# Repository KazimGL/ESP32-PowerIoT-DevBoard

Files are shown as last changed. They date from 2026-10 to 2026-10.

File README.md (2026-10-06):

# ESP32 PowerIoT Dev Board

**A battery-powered ESP32 development board with onboard Li-ion charging, protection, regulation, and sensor support — designed end-to-end in KiCad.**

Designed by **Kazim Bhojani** ([KaizBuilts](#)) — a fresher PCB design project built to learn the complete hardware design workflow from schematic to fabrication-ready Gerbers.

---

## 📋 Overview

This board combines four functional subsystems into a single 2-layer PCB:

| Block | Function |
|---|---|
| **Power** | USB-C input, ESD protection, TP4056 Li-ion charging, DW01A + FS8205A battery protection, AP2112K-3.3 regulation, battery voltage sensing |
| **Processor** | ESP32-WROOM-32E module with reset/boot circuitry |
| **Communication** | CH340C USB-UART bridge with auto-program (DTR/RTS reset) circuit, I2C breakout |
| **I/O** | Dual GPIO breakout headers (1×15 each), user LED, user button, BME280 environmental sensor |

---

## ⚙️ Specs

- **MCU:** ESP32-WROOM-32E (WiFi + Bluetooth)
- **Charging:** TP4056, USB-C input, configurable charge current
- **Protection:** DW01A + FS8205A (overcharge / overdischarge / short-circuit)
- **Regulation:** AP2112K-3.3, 600mA LDO
- **Sensor:** BME280 (temperature, humidity, pressure) over I2C
- **Layers:** 2-layer PCB
- **Design tool:** KiCad 10.0.5
- **Board size:** ~65mm × 50mm

---

## 🖼️ Images

**PCB Layout / Routing**
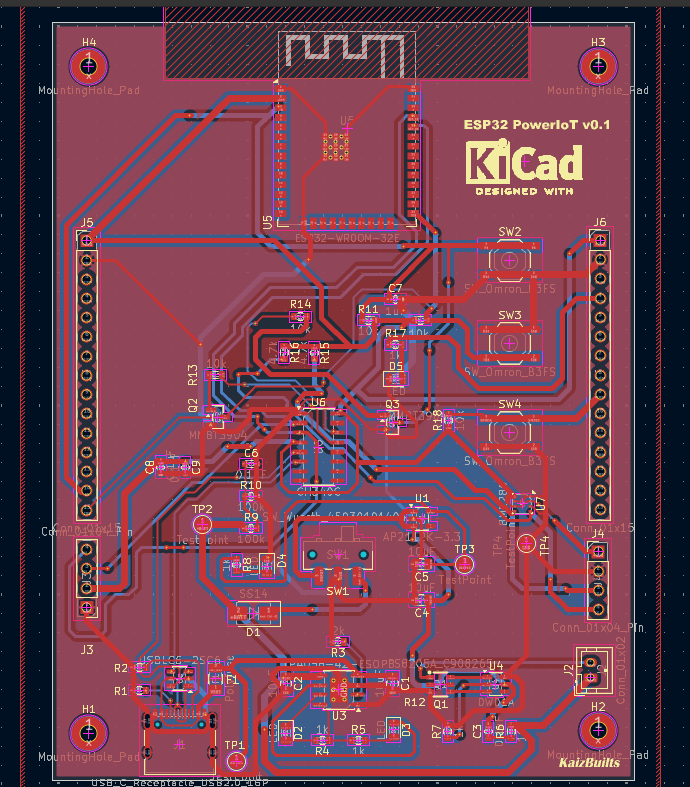
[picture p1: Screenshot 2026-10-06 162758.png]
PCB Routing


**3D Render**
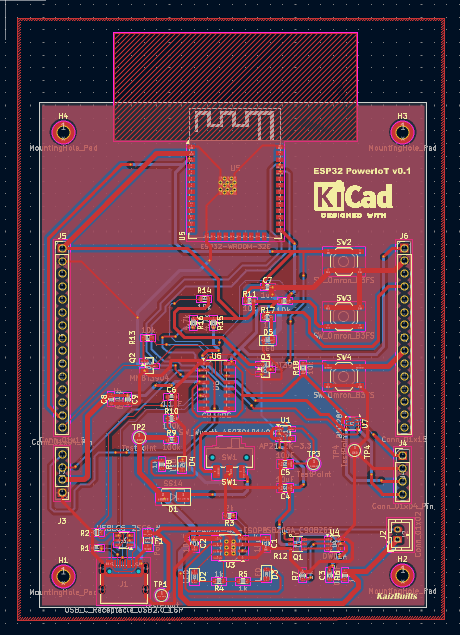
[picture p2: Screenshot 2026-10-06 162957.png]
PCB 3D Render


**Schematic**
📄 [schematic.pdf](schematic.pdf)

**3D Design Overview**
📄 [PRoject_cv.pdf](PRoject_cv.pdf)

---

## 🧠 Design Process & AI-Assisted Workflow

This project was built while learning PCB design fundamentals from scratch, using **Claude (Anthropic)** as a design-review assistant throughout the process — not to generate the design automatically, but to:

- Review each schematic block (Power, Processor, Communication, I/O) for wiring correctness before moving forward
- Explain *why* certain circuits work the way they do (e.g., the EN/IO0 auto-reset logic, battery protection MOSFET gate drive, I2C pull-up sizing)
- Walk through ERC/DRC error messages line-by-line and explain root causes rather than just handing over a fix
- Catch real mistakes along the way (several were my own, and at least one was the AI's — an incorrect DTR/RTS pin mapping that was caught and corrected by cross-checking against esptool's actual reset sequence rather than assumption)

This was an intentionally iterative process: wire a section → verify in ERC → get it reviewed → fix → repeat. Every connection in this board was manually drawn, checked, and understood — the AI's role was review and explanation, not auto-generation.

---

## 🐛 Real Issues Faced During This Build

Documenting these because they were the most time-consuming (and most educational) parts of the project:

1. **KiCad global symbol library table accidentally broken** — while trying to fix a missing footprint library path, the entire global symbol library table collapsed down to a single broken entry, causing 72 cascading ERC warnings across unrelated components (`power`, `Diode`, `Switch`, `Connector` libraries all failed to load). Fixed using KiCad's **"Reset Libraries"** button in the Symbol Libraries manager.

2. **Custom part (FS8205A) had no native KiCad footprint** — imported via `easyeda2kicad` from its LCSC part number, which required linking both a symbol library *and* a separate footprint library (`.pretty` folder) through two different dialogs in two different KiCad editors (Schematic Editor vs. PCB Editor) — not obvious at first.

3. **Duplicate global labels merging unrelated nets** — reused generic labels like `INPUT` and `OUTPUT` in multiple places on the schematic, which KiCad silently merged into a single net across the whole sheet, causing misleading ERC warnings until traced back and renamed to unique, meaningful net names (`VBUS_FUSED`, `3V3`, `-BATT`, etc).

4. **USB-C footprint/symbol pin-count mismatch** — J1 was assigned a 6-pin "power only" USB-C footprint while the schematic symbol used the full 16-pin USB 2.0 pinout (including D+/D−), causing 10 pad-not-found errors during PCB sync. Fixed by selecting the correct 16-pin footprint (`USB_C_Receptacle_HRO_TYPE-C-31-M-12`) matching the real connector's datasheet.

5. **Invalid reference designators blocking PCB sync** — two LED symbols were accidentally named `Green(Done)1` and `RED(charging)1` instead of standard alphanumeric designators, which KiCad's schematic/ERC tolerated but the PCB sync step rejected outright. Renamed to proper `D4`/`D5` format.

6. **DRC hole-size violation on the ESP32 module footprint** — the ESP32-WROOM-32E footprint's castellated pads required a 0.2mm minimum drill size, but the board's design rules were set to a 0.3mm minimum, causing 21 repeated violations. Resolved by adjusting the board's minimum drill size constraint to match both the footprint and the target fab's actual capability.

7. **Incomplete thermal relief connections** on copper pour zones for small shield/ground pads — fixed by reducing the thermal relief gap and spoke width settings to better fit smaller pad geometries.

Each of these was worked through methodically: understand the error → identify root cause → fix → re-verify, rather than blindly applying fixes.

---

## 📁 Repository Contents

```
project_CV.kicad_pro    → KiCad project file
project_CV.kicad_sch    → Schematic source
project_CV.kicad_pcb    → PCB layout source
schematic.pdf           → Exported schematic (all 4 blocks)
PRoject_cv.pdf          → Full project document
*.png                   → PCB layout / 3D render screenshots
README.md               → This file
```

---

## 🔧 Tools Used

- **KiCad 10.0.5** — schematic capture, PCB layout, DRC/ERC
- **easyeda2kicad** — custom part import (FS8205A battery protection MOSFET)
- **Claude (Anthropic)** — design review and debugging assistant

---

---

*Built as a learning project to understand the full PCB design lifecycle — schematic capture, component selection, DFM, fabrication file generation, and bring-up — end to end.*

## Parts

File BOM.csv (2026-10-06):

Reference | Qty | Value | DNP | Exclude from BOM | Exclude from Board | Exclude from Simulation | Exclude from Position Files | Footprint | Datasheet
C1,C2,C4,C5 | 4 | 10uF |  |  |  |  | ${EXCLUDE_FROM_POS_FILES} | Capacitor_SMD:C_0805_2012Metric
C3,C6,C8,C9 | 4 | 0.1uF |  |  |  |  | ${EXCLUDE_FROM_POS_FILES} | Capacitor_SMD:C_0603_1608Metric
C7 | 1 | 1uF |  |  |  |  | ${EXCLUDE_FROM_POS_FILES} | Capacitor_SMD:C_0603_1608Metric
D1 | 1 | SS14 |  |  |  |  | ${EXCLUDE_FROM_POS_FILES} | Diode_SMD:D_SMA | https://www.vishay.com/docs/88746/ss12.pdf
D2,D3,D4,D5 | 4 | LED |  |  |  |  | ${EXCLUDE_FROM_POS_FILES} | LED_SMD:LED_0805_2012Metric
F1 | 1 | Polyfuse |  |  |  |  | ${EXCLUDE_FROM_POS_FILES} | Fuse:Fuse_1206_3216Metric
J1 | 1 | USB_C_Receptacle_USB2.0_16P |  |  |  |  | ${EXCLUDE_FROM_POS_FILES} | Connector_USB:USB_C_Receptacle_HRO_TYPE-C-31-M-12 | https://www.usb.org/sites/default/files/documents/usb_type-c.zip
J2 | 1 | Conn_01x02 |  |  |  |  | ${EXCLUDE_FROM_POS_FILES} | Connector_JST:JST_PH_B2B-PH-K_1x02_P2.00mm_Vertical
J3,J4 | 2 | Conn_01x04_Pin |  |  |  |  | ${EXCLUDE_FROM_POS_FILES} | Connector_PinHeader_2.54mm:PinHeader_1x04_P2.54mm_Vertical
J5,J6 | 2 | Conn_01x15 |  |  |  |  | ${EXCLUDE_FROM_POS_FILES} | Connector_PinHeader_2.54mm:PinHeader_1x15_P2.54mm_Vertical
Q1 | 1 | FS8205A_C908265 |  |  |  |  | ${EXCLUDE_FROM_POS_FILES} | FS8205A_lib:SOT-23-6_L2.9-W1.6-P0.95-LS2.8-BR | https://lcsc.com/product-detail/MOSFET_FUXINSEMI-FS8205A_C908265.html
Q2,Q3 | 2 | MMBT3904 |  |  |  |  | ${EXCLUDE_FROM_POS_FILES} | Package_TO_SOT_SMD:SOT-23 | https://www.onsemi.com/pdf/datasheet/pzt3904-d.pdf
R1,R2 | 2 | 5.1k |  |  |  |  | ${EXCLUDE_FROM_POS_FILES} | Resistor_SMD:R_0603_1608Metric
R3 | 1 | 2k |  |  |  |  | ${EXCLUDE_FROM_POS_FILES} | Resistor_SMD:R_0603_1608Metric
R4,R5,R7,R8,R17 | 5 | 1k |  |  |  |  | ${EXCLUDE_FROM_POS_FILES} | Resistor_SMD:R_0603_1608Metric
R6 | 1 | 100 |  |  |  |  | ${EXCLUDE_FROM_POS_FILES} | Resistor_SMD:R_0603_1608Metric
R9,R10 | 2 | 100k |  |  |  |  | ${EXCLUDE_FROM_POS_FILES} | Resistor_SMD:R_0603_1608Metric
R11,R12,R13,R14,R18 | 5 | 10k |  |  |  |  | ${EXCLUDE_FROM_POS_FILES} | Resistor_SMD:R_0603_1608Metric
R15,R16 | 2 | 4.7k |  |  |  |  | ${EXCLUDE_FROM_POS_FILES} | Resistor_SMD:R_0603_1608Metric
SW1 | 1 | SW_Wuerth_450301014042 |  |  |  |  | ${EXCLUDE_FROM_POS_FILES} | Button_Switch_SMD:SW_SPDT_CK_JS102011SAQN | https://www.we-online.com/components/products/datasheet/450301014042.pdf
SW2,SW3,SW4 | 3 | SW_Omron_B3FS |  |  |  |  | ${EXCLUDE_FROM_POS_FILES} | Button_Switch_SMD:SW_SPST_TL3342 | https://omronfs.omron.com/en_US/ecb/products/pdf/en-b3fs.pdf
TP1,TP2,TP3,TP4 | 4 | TestPoint |  |  |  |  | ${EXCLUDE_FROM_POS_FILES} | TestPoint:TestPoint_Pad_D2.0mm
U1 | 1 | AP2112K-3.3 |  |  |  |  | ${EXCLUDE_FROM_POS_FILES} | Package_TO_SOT_SMD:SOT-23-5 | https://www.diodes.com/assets/Datasheets/AP2112.pdf
U2 | 1 | USBLC6-2SC6 |  |  |  |  | ${EXCLUDE_FROM_POS_FILES} | Package_TO_SOT_SMD:SOT-23-6 | https://www.st.com/resource/en/datasheet/usblc6-2.pdf
U3 | 1 | TP4056-42-ESOP8 |  |  |  |  | ${EXCLUDE_FROM_POS_FILES} | Package_SO:SOIC-8-1EP_3.9x4.9mm_P1.27mm_EP2.41x3.3mm_ThermalVias | https://www.lcsc.com/datasheet/lcsc_datasheet_2410121619_TOPPOWER-Nanjing-Extension-Microelectronics-TP4056-42-ESOP8_C16581.pdf
U4 | 1 | DW01A |  |  |  |  | ${EXCLUDE_FROM_POS_FILES} | Package_TO_SOT_SMD:SOT-23-6 | https://hmsemi.com/downfile/DW01A.PDF
U5 | 1 | ESP32-WROOM-32E |  |  |  |  | ${EXCLUDE_FROM_POS_FILES} | RF_Module:ESP32-WROOM-32E | https://www.espressif.com/sites/default/files/documentation/esp32-wroom-32e_esp32-wroom-32ue_datasheet_en.pdf
U6 | 1 | CH340C |  |  |  |  | ${EXCLUDE_FROM_POS_FILES} | Package_SO:SOIC-16_3.9x9.9mm_P1.27mm | https://datasheet.lcsc.com/szlcsc/Jiangsu-Qin-Heng-CH340C_C84681.pdf
U7 | 1 | BME280 |  |  |  |  | ${EXCLUDE_FROM_POS_FILES} | Package_LGA:Bosch_LGA-8_2.5x2.5mm_P0.65mm_ClockwisePinNumbering | https://www.bosch-sensortec.com/media/boschsensortec/downloads/datasheets/bst-bme280-ds002.pdf

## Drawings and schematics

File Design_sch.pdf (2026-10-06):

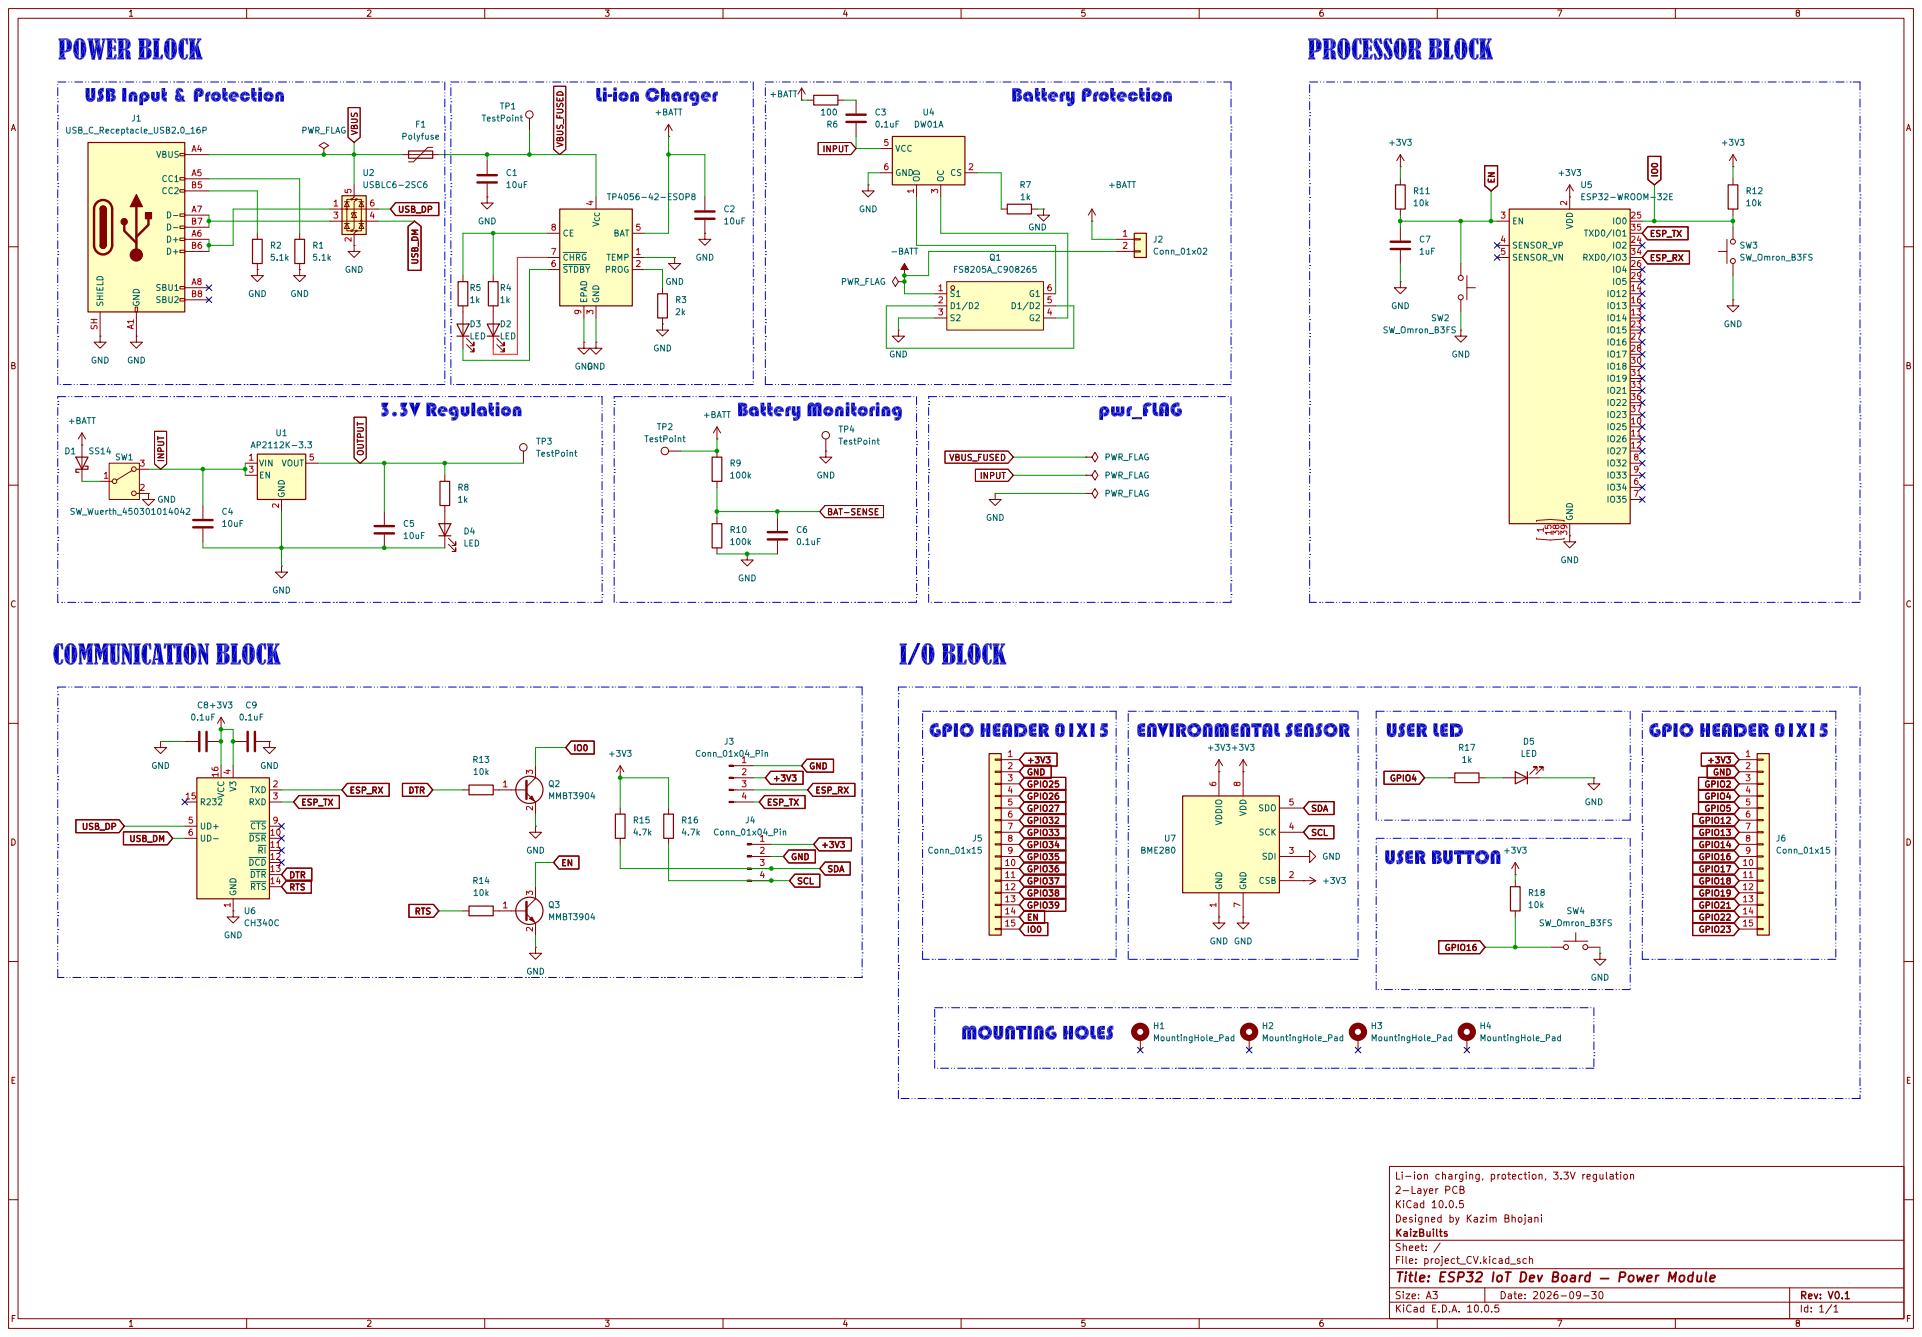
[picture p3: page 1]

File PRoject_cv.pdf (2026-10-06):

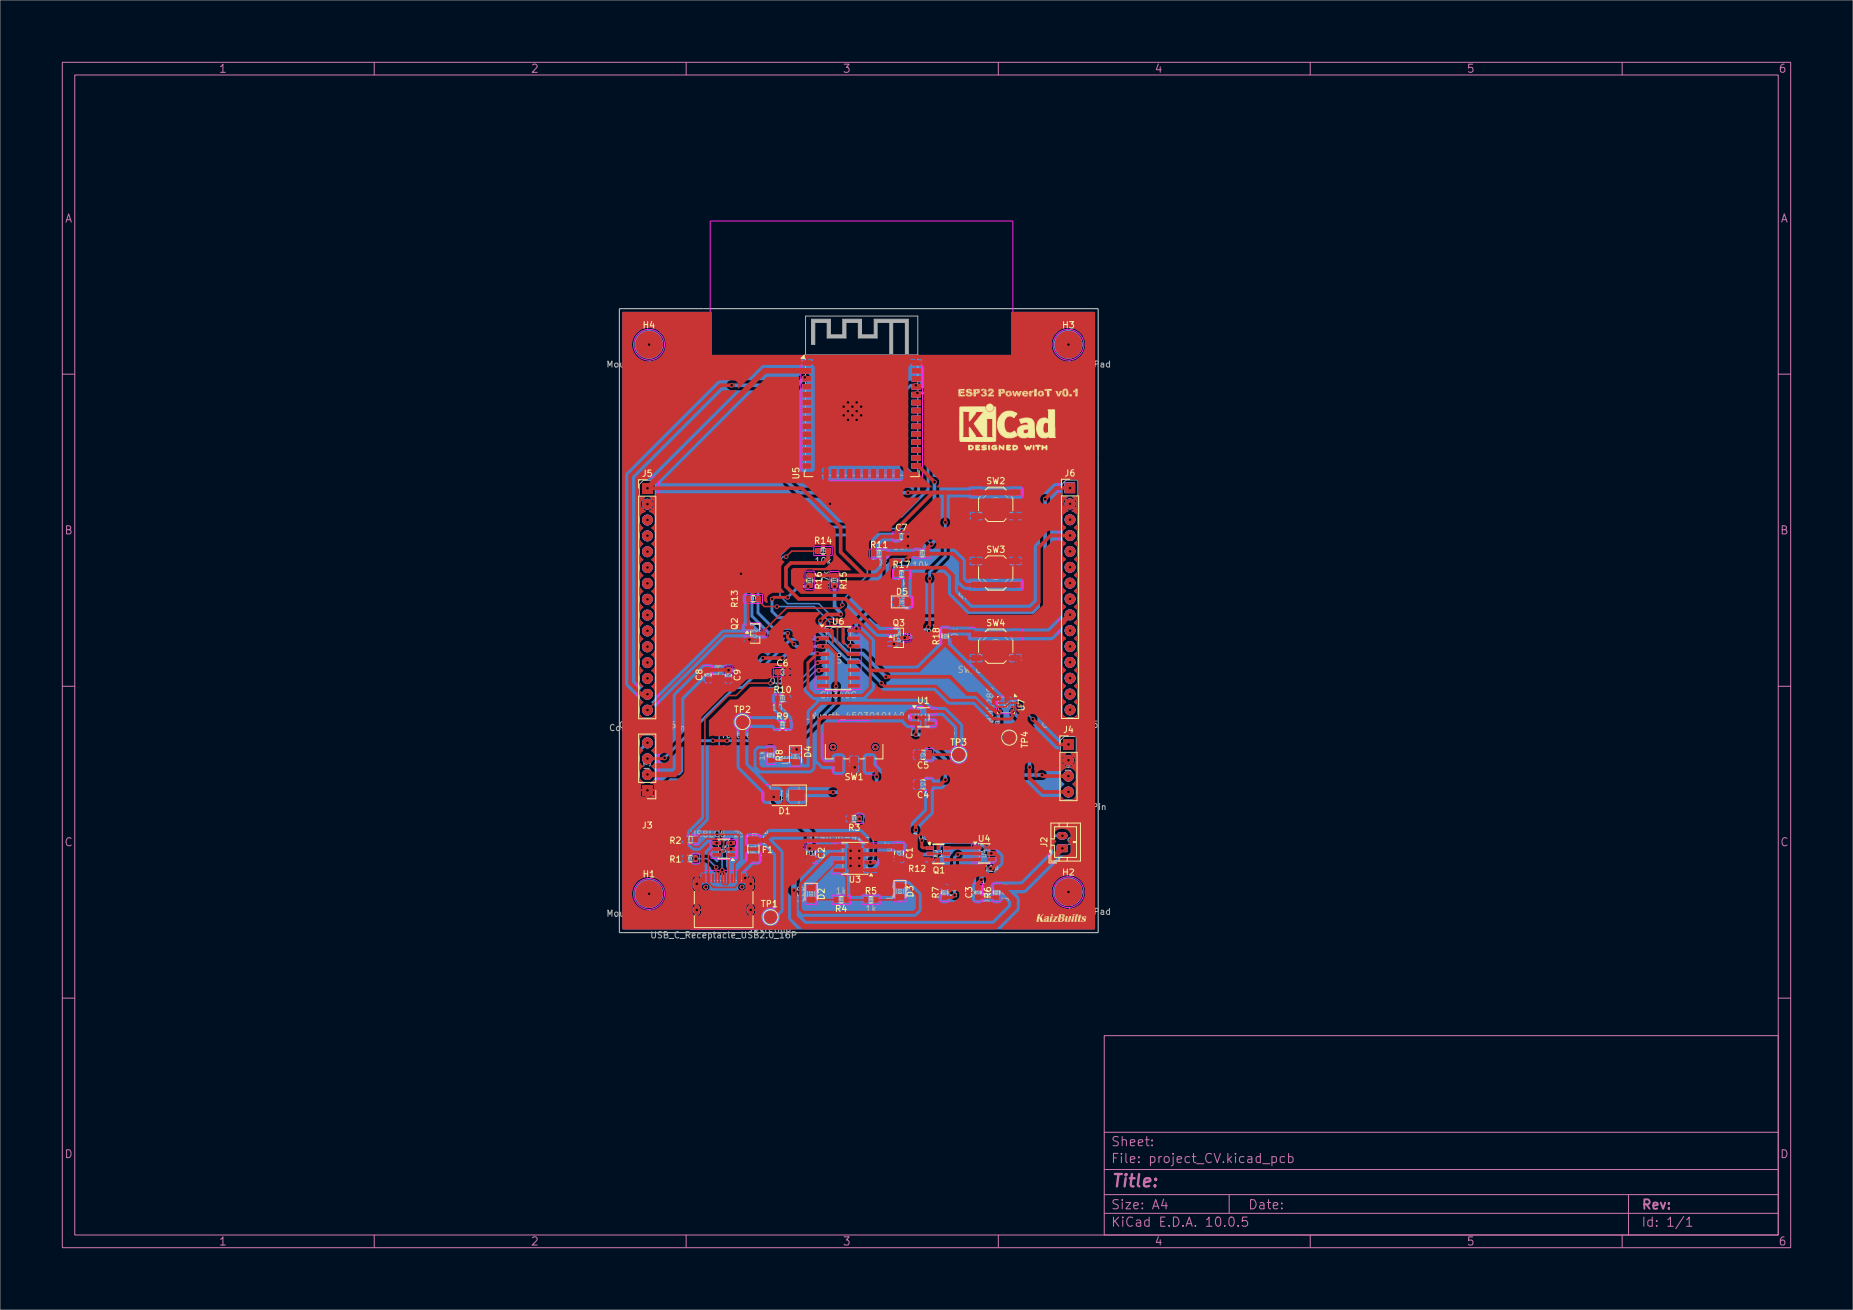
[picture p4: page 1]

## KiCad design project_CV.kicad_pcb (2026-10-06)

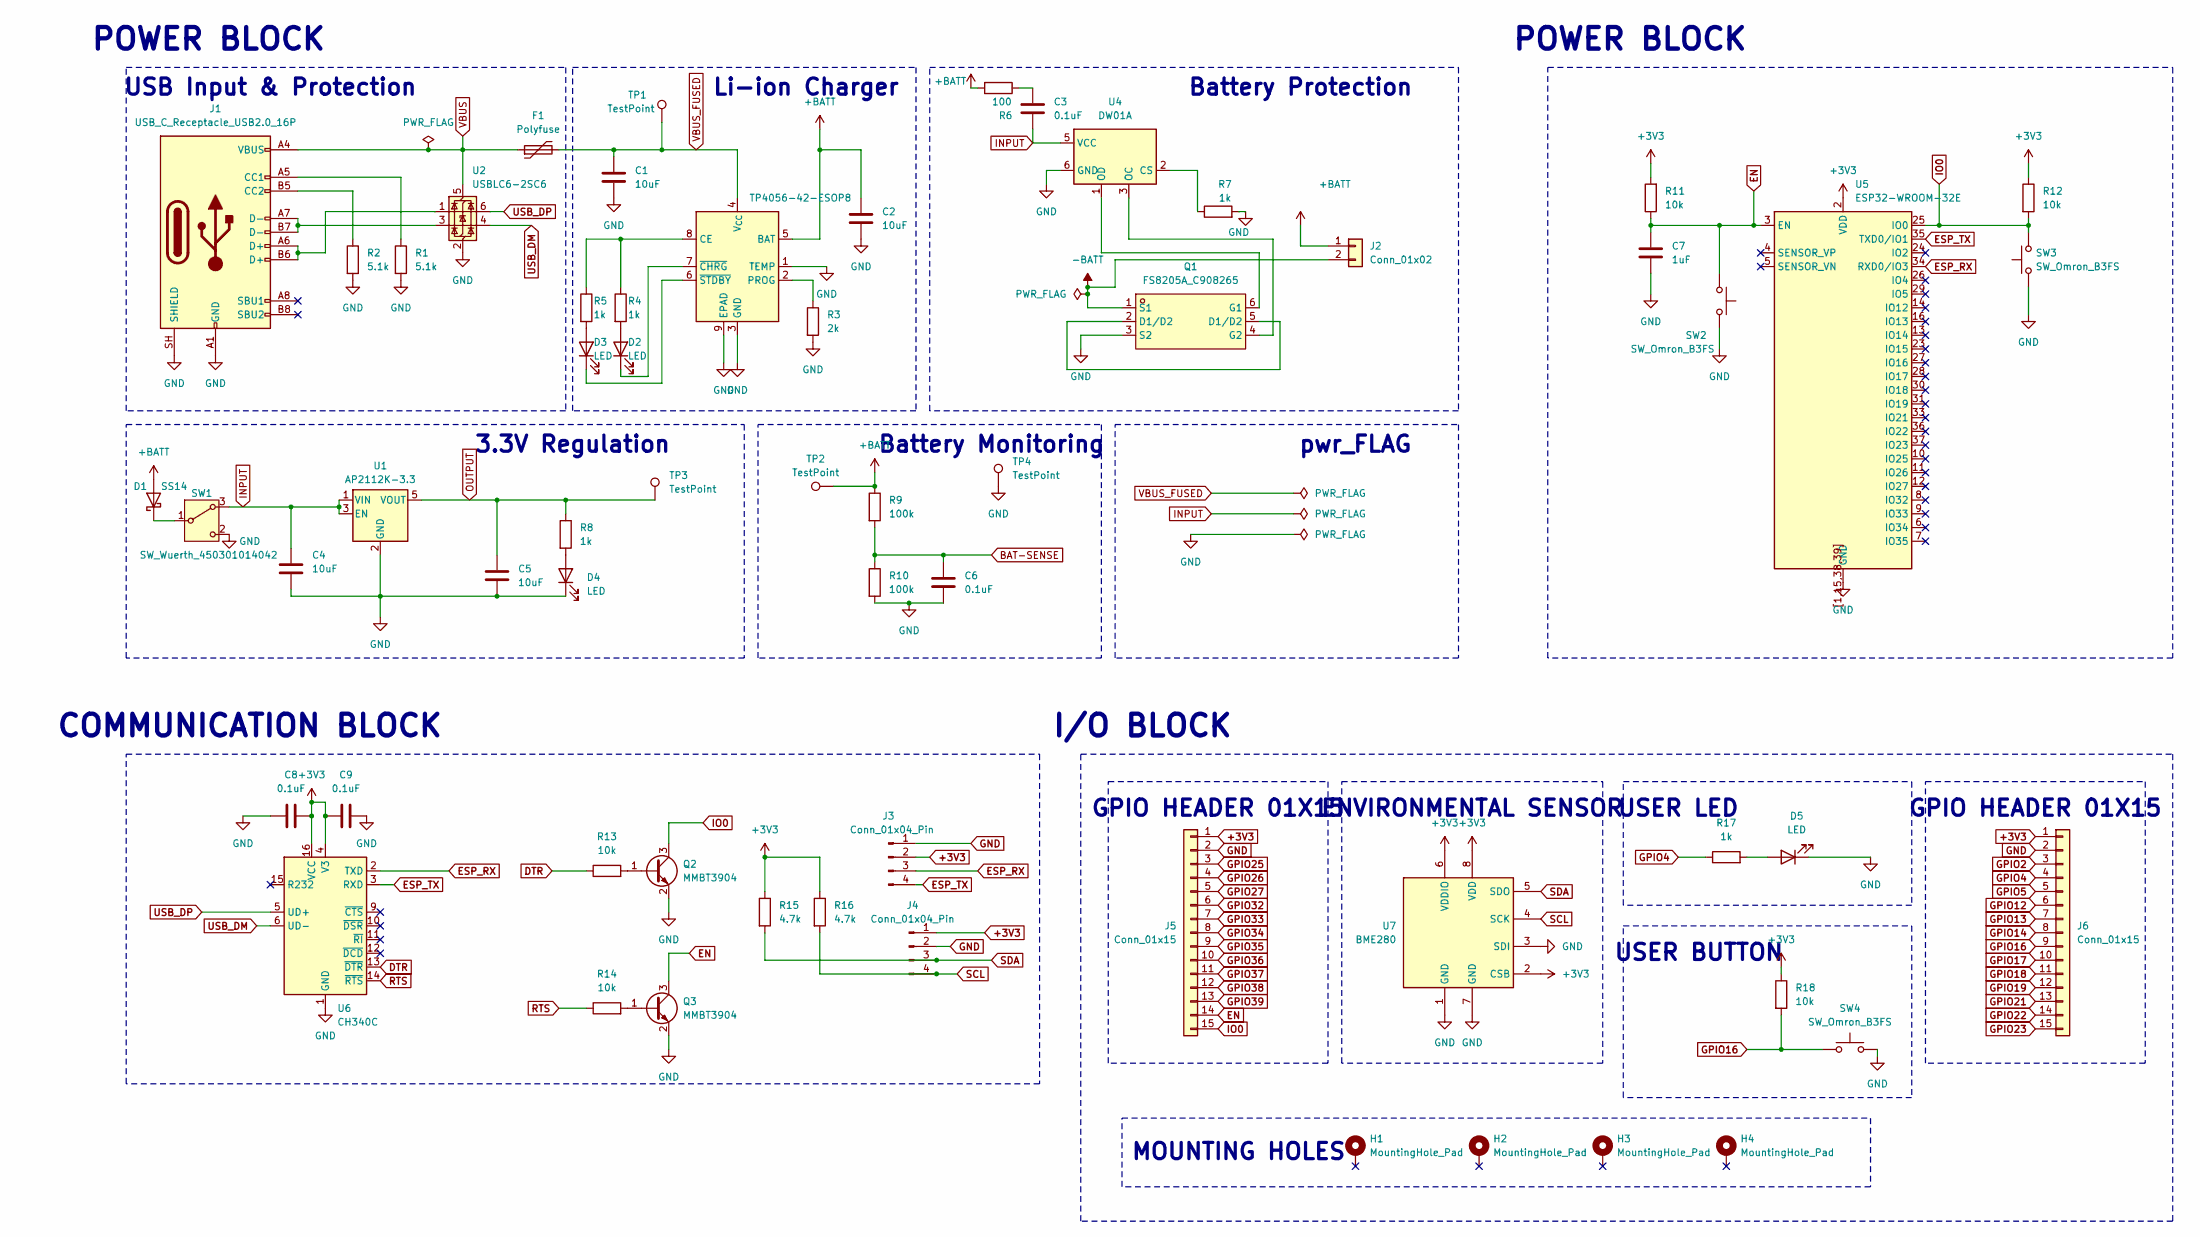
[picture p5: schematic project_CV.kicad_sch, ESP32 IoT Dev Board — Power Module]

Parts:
C1, C2, C4, C5: 10uF; C_0805_2012Metric
C3, C6, C8, C9: 0.1uF; C_0603_1608Metric
C7: 1uF; C_0603_1608Metric
D1: SS14; D_SMA
D2, D3, D4, D5: LED; LED_0805_2012Metric
F1: Polyfuse; Fuse_1206_3216Metric
H1, H2, H3, H4: MountingHole_Pad; MountingHole_2.2mm_M2_Pad
J1: USB_C_Receptacle_USB2.0_16P; USB_C_Receptacle_HRO_TYPE-C-31-M-12
J2: Conn_01x02; JST_PH_B2B-PH-K_1x02_P2.00mm_Vertical
J3, J4: Conn_01x04_Pin; PinHeader_1x04_P2.54mm_Vertical
J5, J6: Conn_01x15; PinHeader_1x15_P2.54mm_Vertical
Q1: FS8205A_C908265; SOT-23-6_L2.9-W1.6-P0.95-LS2.8-BR; MPN FS8205A; LCSC Part C908265
Q2, Q3: MMBT3904; SOT-23
R1, R2: 5.1k; R_0603_1608Metric
R3: 2k; R_0603_1608Metric
R4, R5, R7, R8, R17: 1k; R_0603_1608Metric
R6: 100; R_0603_1608Metric
R9, R10: 100k; R_0603_1608Metric
R11, R12, R13, R14, R18: 10k; R_0603_1608Metric
R15, R16: 4.7k; R_0603_1608Metric
SW1: SW_Wuerth_450301014042; SW_SPDT_CK_JS102011SAQN
SW2, SW3, SW4: SW_Omron_B3FS; SW_SPST_TL3342
TP1, TP2, TP3, TP4: TestPoint; TestPoint_Pad_D2.0mm
U1: AP2112K-3.3; SOT-23-5
U2: USBLC6-2SC6; SOT-23-6
U3: TP4056-42-ESOP8; SOIC-8-1EP_3.9x4.9mm_P1.27mm_EP2.41x3.3mm_ThermalVias
U4: DW01A; SOT-23-6
U5: ESP32-WROOM-32E
U6: CH340C; SOIC-16_3.9x9.9mm_P1.27mm
U7: BME280; Bosch_LGA-8_2.5x2.5mm_P0.65mm_ClockwisePinNumbering

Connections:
+3V3: C8.2, C9.1, J3.2, J4.1, J5.1, J6.1, R11.2, R12.1, R15.1, R16.1, R18.1, U5.2 (VDD), U6.4 (V3), U6.16 (VCC), U7.2 (CSB), U7.6 (VDDIO), U7.8 (VDD)
+BATT: C2.1, D1.2 (A), J2.1, R6.2, R9.1, TP2.1 (1_1), U3.5 (BAT)
-BATT: J2.2, Q1.1 (S1)
BAT-SENSE: C6.1, R9.2, R10.1
DTR: R13.1, U6.13 (~DTR)
EN: C7.1, J5.14, Q3.3 (C), R11.1, SW2.1, U5.3 (EN)
ESP_RX: J3.3, U5.34 (RXD0/IO3), U6.2 (TXD)
ESP_TX: J3.4, U5.35 (TXD0/IO1), U6.3 (RXD)
GND: C1.2, C2.2, C4.2, C5.2, C6.2, C7.2, C8.1, C9.2, D4.1 (K), D5.1 (K), J1.A1 (GND), J1.A12 (GND), J1.B1 (GND), J1.B12 (GND), J1.SH (SHIELD), J3.1, J4.2, J5.2, J6.2, Q1.3 (S2), Q2.2 (E), Q3.2 (E), R1.2, R2.2, R3.2, R7.2, R10.2, SW1.2 (C), SW2.2, SW3.1, SW4.2, TP4.1 (1_1), U1.2 (GND), U2.2 (GND), U3.1 (TEMP), U3.3 (GND), U3.9 (EPAD), U4.6 (GND), U5.1 (GND), U5.15 (GND), U5.38 (GND), U5.39 (GND), U5.[1,15,38,39] (GND), U6.1 (GND), U7.1 (GND), U7.3 (SDI), U7.7 (GND); also elsewhere on the board
GPIO2: J6.3
GPIO4: J6.4, R17.1
GPIO5: J6.5
GPIO12: J6.6
GPIO13: J6.7
GPIO14: J6.8
GPIO16: J6.9, R18.2, SW4.1
GPIO17: J6.10
GPIO18: J6.11
GPIO19: J6.12
GPIO21: J6.13
GPIO22: J6.14
GPIO23: J6.15
GPIO25: J5.3
GPIO26: J5.4
GPIO27: J5.5
GPIO32: J5.6
GPIO33: J5.7
GPIO34: J5.8
GPIO35: J5.9
GPIO36: J5.10
GPIO37: J5.11
GPIO38: J5.12
GPIO39: J5.13
INPUT: C3.2, C4.1, SW1.3 (A), U1.1 (VIN), U1.3 (EN), U4.5 (VCC)
IO0: J5.15, Q2.3 (C), R12.2, SW3.2, U5.25 (IO0)
unnamed: C3.1, R6.1
unnamed: D1.1 (K), SW1.1 (B)
unnamed: D2.2 (A), R4.2
unnamed: D2.1 (K), U3.7 (~CHRG)
unnamed: D3.2 (A), R5.2
unnamed: D3.1 (K), U3.6 (~STDBY)
unnamed: D4.2 (A), R8.2
unnamed: D5.2 (A), R17.2
unnamed: J1.A5 (CC1), R1.1
unnamed: J1.B5 (CC2), R2.1
unnamed 45: J1.A6 (D+), J1.B6 (D+), U2.1 (I/O1); also elsewhere on the board
unnamed 46: J1.A7 (D-), J1.B7 (D-), U2.3 (I/O2); also elsewhere on the board
unnamed: Q1.2 (D1/D2), Q1.5 (D1/D2)
unnamed: Q1.6 (G1), U4.1 (OD)
unnamed: Q1.4 (G2), U4.3 (OC)
unnamed: Q2.1 (B), R13.2
unnamed: Q3.1 (B), R14.2
unnamed: R4.1, R5.1, U3.8 (CE)
unnamed: R3.1, U3.2 (PROG)
unnamed: R7.1, U4.2 (CS)
OUTPUT: C5.1, R8.1, TP3.1 (1_1), U1.5 (VOUT)
RTS: R14.1, U6.14 (~RTS)
SCL: J4.4, R16.2, U7.4 (SCK)
SDA: J4.3, R15.2, U7.5 (SDO)
USB_DM: U2.4 (I/O2), U6.6 (UD-); also elsewhere on the board
USB_DP: U2.6 (I/O1), U6.5 (UD+); also elsewhere on the board
VBUS: F1.1, J1.A4 (VBUS), J1.A9 (VBUS), J1.B4 (VBUS), J1.B9 (VBUS), U2.5 (VBUS); also elsewhere on the board
VBUS_FUSED: C1.1, F1.2, TP1.1 (1_1), U3.4 (V_{CC})

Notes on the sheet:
3.3V Regulation
COMMUNICATION BLOCK
USER BUTTON
GPIO HEADER 01X15
I/O BLOCK
Battery Monitoring
USER LED
POWER BLOCK
Li-ion Charger
ENVIRONMENTAL SENSOR
USB Input & Protection
pwr_FLAG
MOUNTING HOLES
Battery Protection

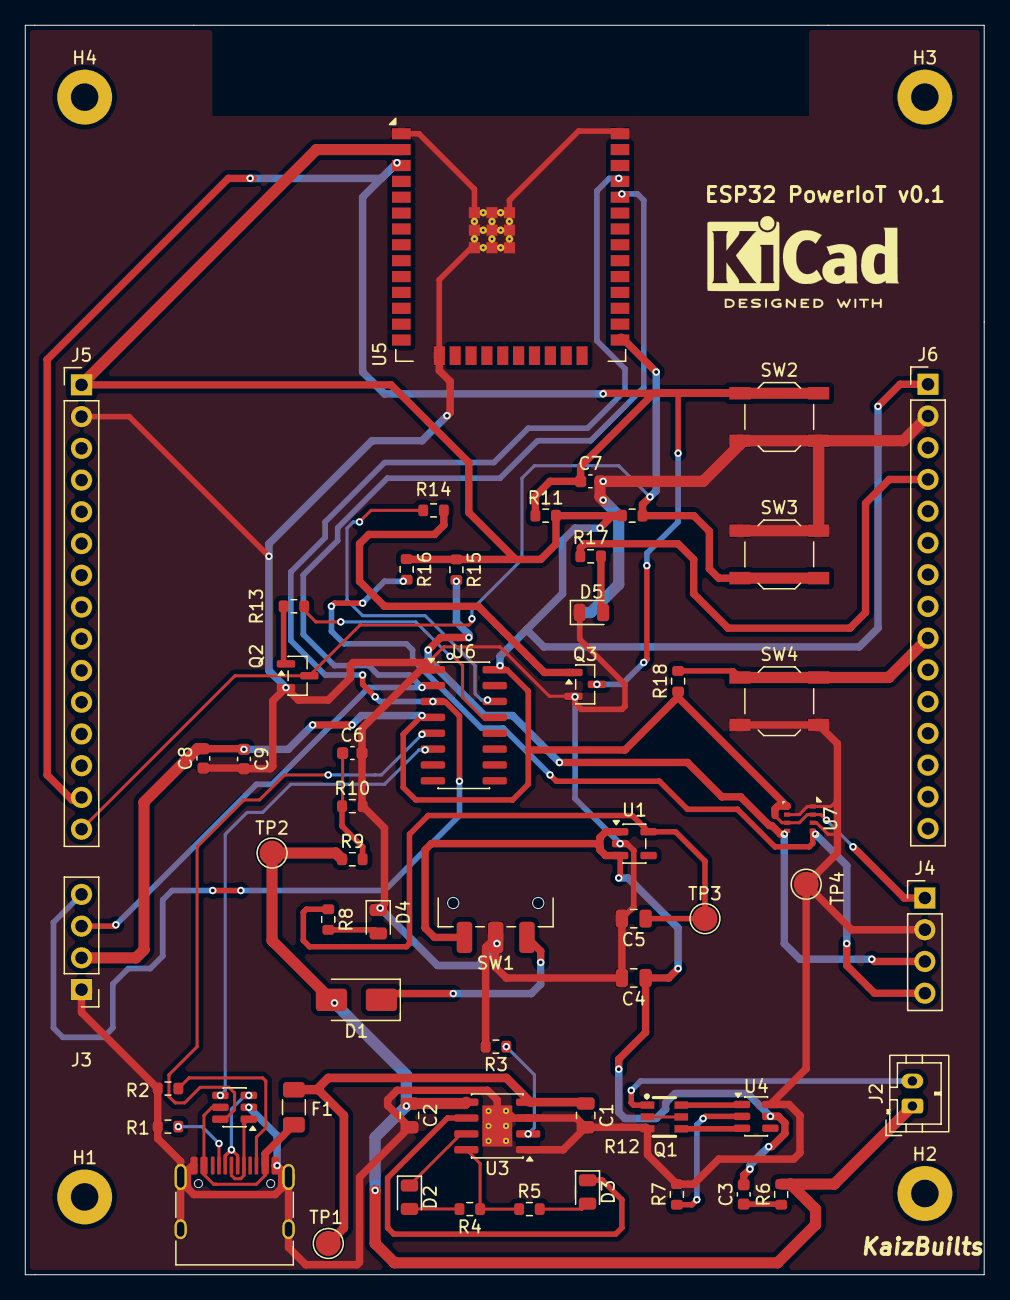
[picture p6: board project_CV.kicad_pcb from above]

Board: 2 copper layers, 76.8 x 100.0 mm, 61 parts (0 on the bottom side), 41 nets.

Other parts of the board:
Ue: USBLC6-2SC6; SOT-23-6

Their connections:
GND: Ue.2 (GND); also elsewhere on the board
unnamed 45: Ue.1 (I/O1); also elsewhere on the board
unnamed 46: Ue.3 (I/O2); also elsewhere on the board
USB_DM: Ue.4 (I/O2); also elsewhere on the board
USB_DP: Ue.6 (I/O1); also elsewhere on the board
VBUS: Ue.5 (VBUS); also elsewhere on the board
